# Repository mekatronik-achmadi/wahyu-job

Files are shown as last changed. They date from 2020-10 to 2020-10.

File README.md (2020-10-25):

This example test toolkit for various RF module.

###### SIM7000E
- [x] Own VDD
- [x] Serial Comm
- [x] Serial Prog
- [x] SIM Card Slot
- [x] GPS Antena
- [x] RF Antena
- [x] Boot-Config Pin
- [x] USB Firmware (R-USB Optional)
- [x] UART-FT232RL
- [x] UART-ESP32

###### ESP32-WROVER-IB
- [x] Own VDD
- [x] Serial Comm
- [x] Serial Prog
- [x] Boot-Config Pin
- [x] RTS-CTS Transistor
- [x] UART-FT232RL
- [x] UART-SIM7000

###### LORA SX1262
- [ ] Own VDD
- [ ] Serial Comm
- [ ] Serial Prog
- [ ] Boot-Config Pin

###### SIM800C
- [ ] Own VDD
- [ ] Serial Comm
- [ ] Serial Prog
- [ ] GPS Antena
- [ ] RF Antena
- [ ] Boot-Config Pin

###### FT232RL
- [x] Global VDD
- [x] Serial Comm
- [x] USB Port
- [x] UART Indicator (Optional)

###### AMS1117-3V3
- [x] Global VDD
- [x] Global VCC
- [x] VDD Selector

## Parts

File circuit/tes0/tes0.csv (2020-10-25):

Id | Designator | Package | Quantity | Designation | Supplier [Code] | Min Qty | URLs
1 | C-S70_ANT_GPS1,C-S70_ANT_GPS2 | C_0805_2012Metric_Pad1.15x1.40mm_HandSolder | 2 | 33pF | Tokopedia [Indoware] | 10 | https://www.tokopedia.com/indo-ware/0805-33pf-33-pf-50v-kapasitor-2012-smd-capasitor-33p-33-p-33-pf-33pf
2 | C-S70_ANT_RF1,C-S70_ANT_RF2 | C_0805_2012Metric_Pad1.15x1.40mm_HandSolder | 2 | C | Tokopedia [Indoware] | 10 | https://www.tokopedia.com/indo-ware/0805-33pf-33-pf-50v-kapasitor-2012-smd-capasitor-33p-33-p-33-pf-33pf
3 | R-S70_ANT_GPS1 | R_0805_2012Metric_Pad1.15x1.40mm_HandSolder | 1 | 10 | Tokopedia [Indoware] | 20 | https://www.tokopedia.com/indo-ware/10r-10-ohm-10-r-0805-1-resistor-smd-10ohm-10-ohm
4 | R-S70_ANT_RF1,R-S70_USB_VBUS1 | R_0805_2012Metric_Pad1.15x1.40mm_HandSolder | 2 | 0 | Tokopedia [Indoware] | 20 | https://www.tokopedia.com/indo-ware/0r-0-ohm-0805-5-paket-1-pcs-resistor-smd-jumper-nol-ohm-jumper-2012
5 | R-S70_USIM1,R-S70_USIM2,R-S70_USIM3 | R_0805_2012Metric_Pad1.15x1.40mm_HandSolder | 3 | 22 | Tokopedia [Indoware] | 20 | https://www.tokopedia.com/indo-ware/22r-22-ohm-0805-5-paket-10-pcs-resistor-smd-1
6 | U3 | SOT-223-3_TabPin2 | 1 | AMS1117-3.3 | Tokopedia [Indoware] | 4 | https://www.tokopedia.com/indo-ware/ams-1117-33v-smd-ams1117-33-voltage-regulated-ic-sot-223-ldo-33v
7 | R-ESP32_BOOT1,R-ESP32_BOOT2 | R_0805_2012Metric_Pad1.15x1.40mm_HandSolder | 2 | 100 | Tokopedia [Indoware] | 10 | https://www.tokopedia.com/indo-ware/100r-100-ohm-0805-5-paket-10-pcs-resistor-smd
8 | C-AMS1,C-AMS2,C-FT_3V3 | C_0805_2012Metric_Pad1.15x1.40mm_HandSolder | 3 | 100nF | Tokopedia | 2 (20) | https://www.tokopedia.com/tentronik/10-pcs-c-capasitor-100nf-100-nf-0-1uf-50v-smd-0805-10
9 | J-S70_ANT_GPS1,J-S70_ANT_RF1 | Taoglas-RECE-20279-001E-01-MFG | 2 | RECE-20279-001E-01 | Tokopedia | 10 | https://www.tokopedia.com/visitek/ipex-original-antenna-base-ipx-20279-001e-antena-u-fl-connector-0-4ghz
10 | L-S70_ANT_GPS1 | L_0805_2012Metric_Pad1.15x1.40mm_HandSolder | 1 | 47nH | Tokopedia | 10 | https://www.tokopedia.com/cosmic-iot/induktor-inductor-smd-47nh-47-nh-0805-error-5
11 | SW-S70-PWR1,SW-S70-RST1,SW-ESP32_RST1,SW-ESP32_RUN1 | SW_PUSH_6mm | 4 | SW_Push | Tokopedia | 10 | https://www.tokopedia.com/ahrar-1/push-button-saklar-kecil-tactile-tact-switch-micro-4pin-4p-6x6x5mm
12 | L-S70_ANT_GPS2,L-S70_ANT_GPS3 | L_0805_2012Metric_Pad1.15x1.40mm_HandSolder | 2 | L | Tokopedia | 10 | https://www.tokopedia.com/cosmic-iot/induktor-inductor-smd-47nh-47-nh-0805-error-5
13 | J-FT_USB1,J-S70-USB1 | USB_Micro-B_Wuerth_629105150521 | 2 | USB_B_Micro | Digiware [919-209] | 4 | https://digiwarestore.com/id/connector/micro-usb-connector-b-type-female-05p-smt-90-919209.html
14 | J-BRD_S70_FT1,J-BRD_ESP32_FT1,J-BRD_S70_ESP1 | PinHeader_2x02_P2.54mm_Vertical | 3 | Conn_02x02_Odd_Even | Digiware [323-074] | 4 | https://digiwarestore.com/id/pcb-male/header-40x2-kw2-323074.html
15 | J-ESP32_PB1,J-S70_PB1 | PinHeader_1x09_P2.54mm_Vertical | 2 | Conn_01x09 | Digiware [323-002] | 8 | https://digiwarestore.com/id/pcb-male/header-40x1-323002.html
16 | Q-ESP32_BOOT1,Q-ESP32_BOOT2 | SOT-23 | 2 | 2N3904 | Digiware [271-014] | 4 | https://digiwarestore.com/id/npn/mmbt3904lt1-smd-sot-23-10-pcs-per-pack-271014.html
17 | D-FT_RXD1,D-FT_TXD1,D-S70_NETLIGHT1,D-S70_STATUS1,D-ESP32_LED1 | LED_1206_3216Metric_Pad1.42x1.75mm_HandSolder | 5 | LED | Digiware [255-036] | 10 | https://digiwarestore.com/id/led/led-red-super-bright-smd1206-255036.html
18 | U2 | SSOP-28_5.3x10.2mm_P0.65mm | 1 | FT232RL | Digiware [166-019] | 3 | https://digiwarestore.com/id/serial-communication/ft232rl-166019.html
19 | U1 | SIMCON_SIM7000E | 1 | SIM7000E | Aliexpress | 2 | https://www.aliexpress.com/item/4001274551033.html
20 | J-S70_USIM1 | microSIM_JAE_SF53S006VCBR2000 | 1 | SIM_Card | Aliexpress | 6 | https://www.aliexpress.com/item/32793672605.html
21 | A1 | XCVR_ESP32-WROVER-I | 1 | ESP32-WROVER-I | Aliexpress | 2 | https://www.aliexpress.com/item/1005001544883473.html
22 | R-FT_RXD1,R-FT_TXD1,R-S70_NETLIGHT1,R-S70_STATUS1,R-ESP32_LED1 | R_0805_2012Metric_Pad1.15x1.40mm_HandSolder | 5 | 330 | Achmadi | 20 | -
23 | R-ESP32_IO2,R-ESP32_RST1 | R_0805_2012Metric_Pad1.15x1.40mm_HandSolder | 2 | 10K | Achmadi | 10 | -
24 | J-BRD_VDD1 | PinHeader_2x04_P2.54mm_Vertical | 1 | Conn_02x04_Odd_Even | - | - | -
25 | J-S70_PA1,J-S70_PC1 | PinHeader_1x06_P2.54mm_Vertical | 2 | Conn_01x06 | - | - | -
26 | J-S70_UART3 | PinHeader_1x03_P2.54mm_Vertical | 1 | Conn_01x03 | - | - | -
27 | J-S70_UPDATE1 | PinHeader_1x02_P2.54mm_Vertical | 1 | Conn_01x02 | - | - | -
28 | J-ESP32_PA1 | PinHeader_1x08_P2.54mm_Vertical | 1 | Conn_01x08 | - | - | -

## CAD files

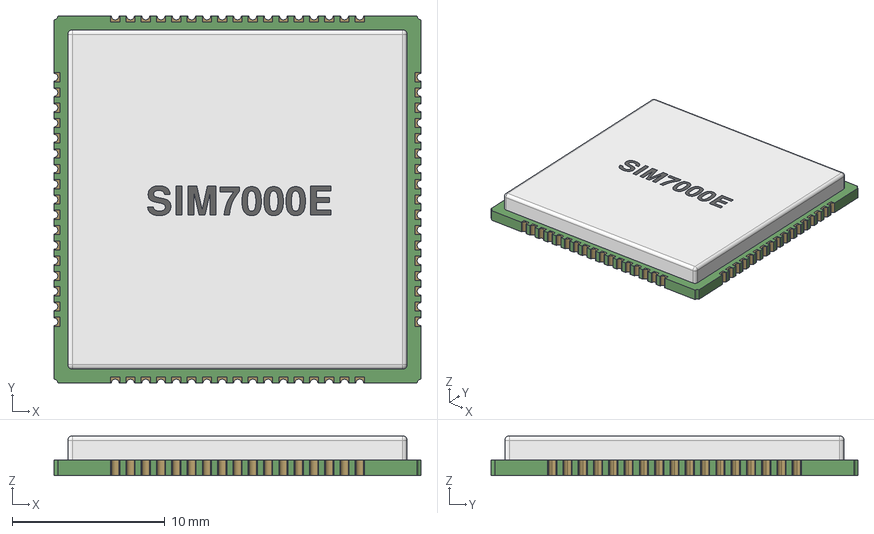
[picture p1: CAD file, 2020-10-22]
circuit/kicadlib/sim7000e/SIM7000.step
24.0 x 24.0 x 2.62 mm

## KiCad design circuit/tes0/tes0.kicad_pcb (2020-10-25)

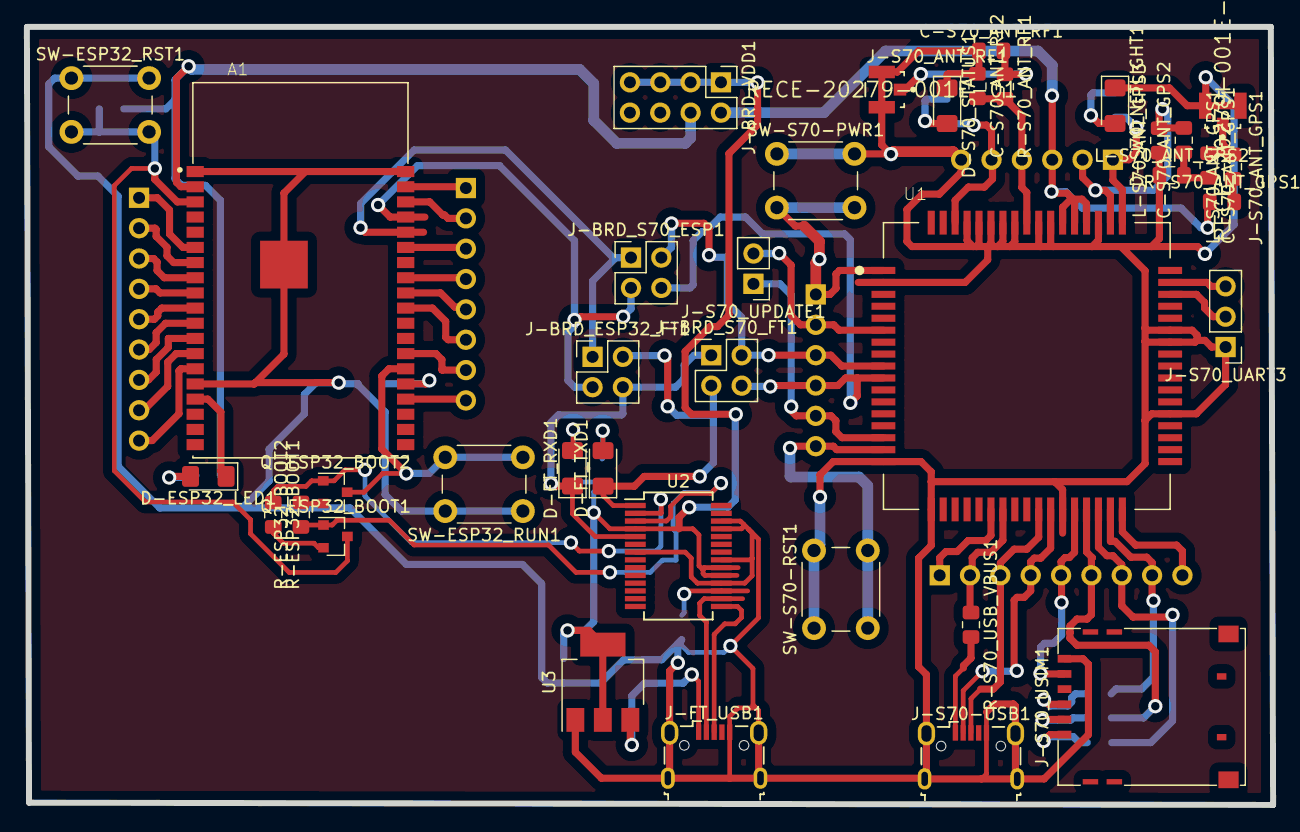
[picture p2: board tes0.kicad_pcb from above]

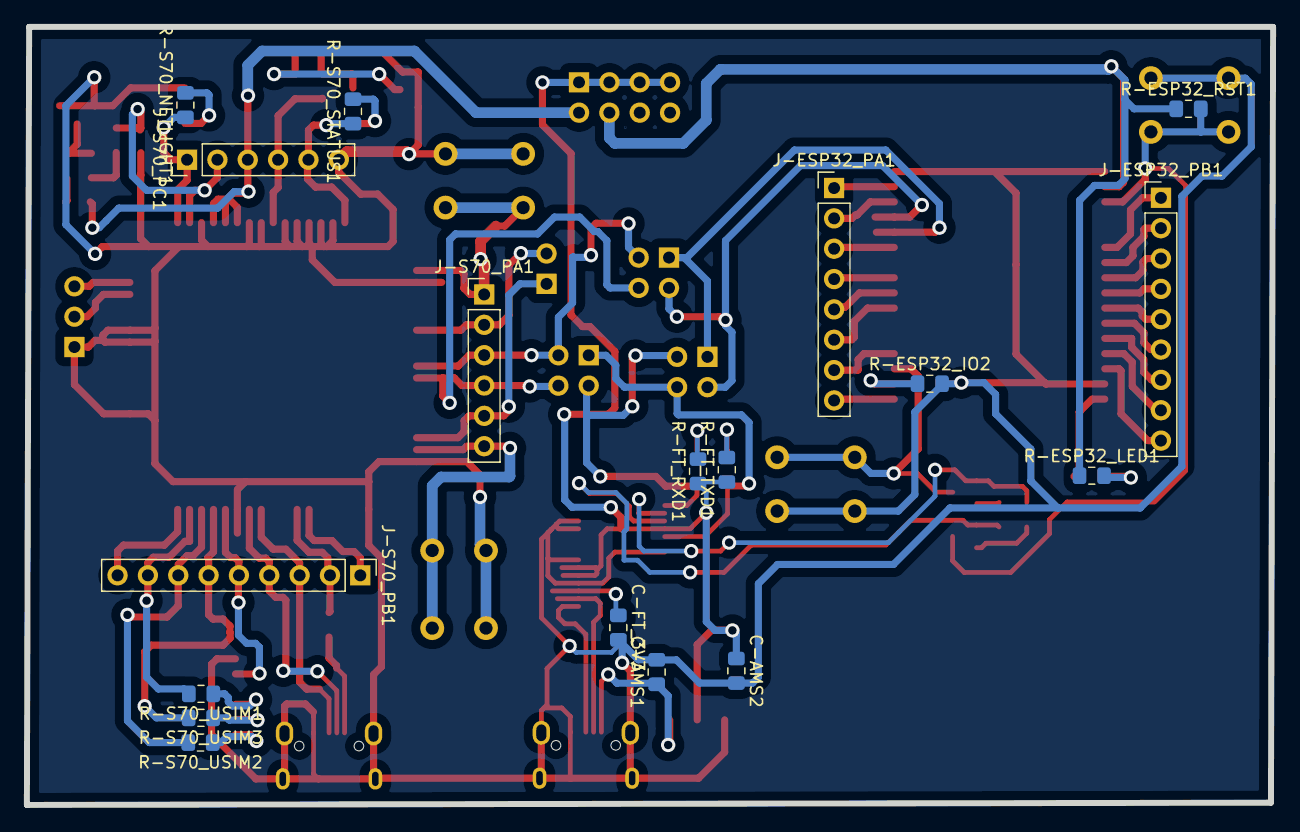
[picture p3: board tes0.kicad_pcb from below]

Board: 2 copper layers, 104.3 x 65.1 mm, 56 parts (18 on the bottom side), 71 nets.

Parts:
A1: ESP32-WROVER-I; XCVR_ESP32-WROVER-I
C-AMS1, C-AMS2: 100nF; C_0805_2012Metric_Pad1.15x1.40mm_HandSolder
C-FT_3V3: 100nF; C_0805_2012Metric_Pad1.15x1.40mm_HandSolder
C-S70_ANT_GPS1, C-S70_ANT_GPS2: 33pF; C_0805_2012Metric_Pad1.15x1.40mm_HandSolder
C-S70_ANT_RF1, C-S70_ANT_RF2: C; C_0805_2012Metric_Pad1.15x1.40mm_HandSolder
D-ESP32_LED1: LED; LED_1206_3216Metric_Pad1.42x1.75mm_HandSolder
D-FT_RXD1: LED; LED_1206_3216Metric_Pad1.42x1.75mm_HandSolder
D-FT_TXD1: LED; LED_1206_3216Metric_Pad1.42x1.75mm_HandSolder
D-S70_NETLIGHT1, D-S70_STATUS1: LED; LED_1206_3216Metric_Pad1.42x1.75mm_HandSolder
J-BRD_ESP32_FT1: Conn_02x02_Odd_Even; PinHeader_2x02_P2.54mm_Vertical
J-BRD_S70_ESP1, J-BRD_S70_FT1: Conn_02x02_Odd_Even; PinHeader_2x02_P2.54mm_Vertical
J-BRD_VDD1: Conn_02x04_Odd_Even; PinHeader_2x04_P2.54mm_Vertical
J-ESP32_PA1: Conn_01x08; PinHeader_1x08_P2.54mm_Vertical
J-ESP32_PB1: Conn_01x09; PinHeader_1x09_P2.54mm_Vertical
J-FT_USB1: USB_B_Micro; USB_Micro-B_Wuerth_629105150521
J-S70-USB1: USB_B_Micro; USB_Micro-B_Wuerth_629105150521
J-S70_ANT_GPS1, J-S70_ANT_RF1: RECE-20279-001E-01; Taoglas-RECE-20279-001E-01-MFG
J-S70_PA1, J-S70_PC1: Conn_01x06; PinHeader_1x06_P2.54mm_Vertical
J-S70_PB1: Conn_01x09; PinHeader_1x09_P2.54mm_Vertical
J-S70_UART3: Conn_01x03; PinHeader_1x03_P2.54mm_Vertical
J-S70_UPDATE1: Conn_01x02; PinHeader_1x02_P2.54mm_Vertical
J-S70_USIM1: SIM_Card; microSIM_JAE_SF53S006VCBR2000
L-S70_ANT_GPS1: 47nH; L_0805_2012Metric_Pad1.15x1.40mm_HandSolder
L-S70_ANT_GPS2, L-S70_ANT_GPS3: L; L_0805_2012Metric_Pad1.15x1.40mm_HandSolder
Q-ESP32_BOOT1, Q-ESP32_BOOT2: 2N3904; SOT-23
R-ESP32_BOOT1, R-ESP32_BOOT2: 100; R_0805_2012Metric_Pad1.15x1.40mm_HandSolder
R-ESP32_IO2, R-ESP32_RST1: 10K; R_0805_2012Metric_Pad1.15x1.40mm_HandSolder
R-ESP32_LED1: 330; R_0805_2012Metric_Pad1.15x1.40mm_HandSolder
R-FT_RXD1: 330; R_0805_2012Metric_Pad1.15x1.40mm_HandSolder
R-FT_TXD1: 330; R_0805_2012Metric_Pad1.15x1.40mm_HandSolder
R-S70_ANT_GPS1: 10; R_0805_2012Metric_Pad1.15x1.40mm_HandSolder
R-S70_ANT_RF1, R-S70_USB_VBUS1: 0; R_0805_2012Metric_Pad1.15x1.40mm_HandSolder
R-S70_NETLIGHT1, R-S70_STATUS1: 330; R_0805_2012Metric_Pad1.15x1.40mm_HandSolder
R-S70_USIM1, R-S70_USIM2, R-S70_USIM3: 22; R_0805_2012Metric_Pad1.15x1.40mm_HandSolder
SW-ESP32_RST1, SW-ESP32_RUN1: SW_Push; SW_PUSH_6mm
SW-S70-PWR1, SW-S70-RST1: SW_Push; SW_PUSH_6mm
U1: SIM7000E; SIMCON_SIM7000E
U2: FT232RL; SSOP-28_5.3x10.2mm_P0.65mm
U3: AMS1117-3.3; SOT-223-3_TabPin2

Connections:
/ESP32_BOOT: A1.25, Q-ESP32_BOOT2.3, SW-ESP32_RUN1.2
/ESP32_IO4: A1.26, J-ESP32_PA1.7
/ESP32_IO5: A1.29, J-ESP32_PA1.6
/ESP32_IO12: A1.14, J-ESP32_PB1.9
/ESP32_IO14: A1.13, J-ESP32_PB1.8
/ESP32_IO15: A1.23, J-ESP32_PA1.8
/ESP32_IO18: A1.30, J-ESP32_PA1.5
/ESP32_IO19: A1.31, J-ESP32_PA1.4
/ESP32_IO21: A1.33, J-ESP32_PA1.3
/ESP32_IO22: A1.36, J-ESP32_PA1.2
/ESP32_IO23: A1.37, J-ESP32_PA1.1
/ESP32_IO25: A1.10, J-ESP32_PB1.5
/ESP32_IO26: A1.11, J-ESP32_PB1.6
/ESP32_IO27: A1.12, J-ESP32_PB1.7
/ESP32_IO32: A1.8, J-ESP32_PB1.3
/ESP32_IO33: A1.9, J-ESP32_PB1.4
/ESP32_IO34: A1.6, J-ESP32_PB1.1
/ESP32_IO35: A1.7, J-ESP32_PB1.2
/ESP32_LED: A1.16, D-ESP32_LED1.1
/ESP32_RST: A1.3, Q-ESP32_BOOT1.3, R-ESP32_RST1.2, SW-ESP32_RST1.2
/ESP32_RXD: A1.34, J-BRD_ESP32_FT1.1, J-BRD_S70_ESP1.1
/ESP32_TXD: A1.35, J-BRD_ESP32_FT1.3, J-BRD_S70_ESP1.3
/ESP32_VDD: A1.2, J-BRD_VDD1.4, R-ESP32_LED1.1, R-ESP32_RST1.1
/FT_DTR: Q-ESP32_BOOT2.1, R-ESP32_BOOT1.1, U2.2
/FT_RTS: Q-ESP32_BOOT1.1, R-ESP32_BOOT2.1, U2.3
/FT_RXD: D-FT_RXD1.1, J-BRD_ESP32_FT1.4, J-BRD_S70_FT1.1, U2.5
/FT_TXD: D-FT_TXD1.1, J-BRD_ESP32_FT1.2, J-BRD_S70_FT1.3, U2.1
/S70_ANT_GPS: C-S70_ANT_GPS2.2, J-S70_PC1.2, L-S70_ANT_GPS3.2, U1.53
/S70_ANT_RF: C-S70_ANT_RF2.2, J-S70_PC1.4, R-S70_ANT_RF1.2, U1.60
/S70_BOOTCFG: J-S70_PA1.2, J-S70_UPDATE1.2, U1.6
/S70_GPIO0: J-S70_UART3.3, U1.50
/S70_GPIO1: J-S70_UART3.2, U1.49
/S70_MDMLOG_TX: J-S70_PB1.1, U1.23
/S70_NETLIGHT: J-S70_PC1.1, R-S70_NETLIGHT1.1, U1.52
/S70_NRST: J-S70_PA1.6, SW-S70-RST1.2, U1.16
/S70_PWRKEY: J-S70_PA1.1, SW-S70-PWR1.2, U1.1
/S70_RXD: J-BRD_S70_ESP1.4, J-BRD_S70_FT1.4, J-S70_PA1.4, U1.10
/S70_STATUS: J-S70_PC1.5, R-S70_STATUS1.1, U1.66
/S70_TXD: J-BRD_S70_ESP1.2, J-BRD_S70_FT1.2, J-S70_PA1.3, U1.9
/S70_USB_DM: J-S70-USB1.2, J-S70_PB1.4, U1.28
/S70_USB_DP: J-S70-USB1.3, J-S70_PB1.3, U1.27
/S70_USB_VBUS: J-S70_PB1.2, R-S70_USB_VBUS1.1, U1.24
/S70_USIM_CLK: J-S70_PB1.7, R-S70_USIM2.2, U1.32
/S70_USIM_DATA: J-S70_PB1.6, R-S70_USIM3.2, U1.31
/S70_USIM_DET: J-S70_PB1.9, U1.34
/S70_USIM_RST: J-S70_PB1.8, R-S70_USIM1.2, U1.33
/S70_USIM_VDD: J-S70_PB1.5, J-S70_USIM1.1, U1.30
/S70_VDD: J-BRD_VDD1.2, J-S70_PC1.3, R-S70_ANT_GPS1.1, U1.55, U1.56, U1.57
/S70_VDDEXT: J-S70_PA1.5, J-S70_UPDATE1.1, U1.15
GND: A1.1, A1.15, A1.38, A1.39, C-AMS1.2, C-AMS2.2, C-FT_3V3.2, C-S70_ANT_RF1.1, C-S70_ANT_RF2.1, D-S70_NETLIGHT1.1, D-S70_STATUS1.1, J-FT_USB1.5, J-FT_USB1.6, J-S70-USB1.5, J-S70-USB1.6, J-S70_ANT_GPS1.2, J-S70_ANT_GPS1.3, J-S70_ANT_RF1.2, J-S70_ANT_RF1.3, J-S70_PC1.6, J-S70_UART3.1, J-S70_USIM1.5, L-S70_ANT_GPS2.1, L-S70_ANT_GPS3.1, R-ESP32_IO2.2, SW-ESP32_RST1.1, SW-ESP32_RUN1.1, SW-S70-PWR1.1, SW-S70-RST1.1, U1.2, U1.17, U1.18, U1.29, U1.39, U1.45, U1.46, U1.54, U1.58, U1.59, U1.61, U1.62, U1.63, U1.64, U1.65, U2.7, U2.18, U2.21, U2.25, U2.26, U3.1
unnamed: A1.24, R-ESP32_IO2.1
unnamed: C-FT_3V3.1, U2.17
unnamed: C-S70_ANT_GPS1.1, J-S70_ANT_GPS1.1, L-S70_ANT_GPS1.2
unnamed: C-S70_ANT_GPS1.2, C-S70_ANT_GPS2.1, L-S70_ANT_GPS2.2
unnamed: C-S70_ANT_RF1.2, J-S70_ANT_RF1.1, R-S70_ANT_RF1.1
unnamed: D-ESP32_LED1.2, R-ESP32_LED1.2
unnamed: D-FT_RXD1.2, R-FT_TXD1.2
unnamed: D-FT_TXD1.2, R-FT_RXD1.2
unnamed: D-S70_NETLIGHT1.2, R-S70_NETLIGHT1.2
unnamed: D-S70_STATUS1.2, R-S70_STATUS1.2
unnamed: J-FT_USB1.2, U2.16
unnamed: J-FT_USB1.3, U2.15
unnamed: J-S70-USB1.1, R-S70_USB_VBUS1.2
unnamed: J-S70_USIM1.2, R-S70_USIM1.1
unnamed: J-S70_USIM1.3, R-S70_USIM2.1
unnamed: J-S70_USIM1.7, R-S70_USIM3.1
unnamed: L-S70_ANT_GPS1.1, R-S70_ANT_GPS1.2
unnamed: Q-ESP32_BOOT1.2, R-ESP32_BOOT1.2
unnamed: Q-ESP32_BOOT2.2, R-ESP32_BOOT2.2
VCC: C-AMS1.1, J-FT_USB1.1, U3.3
VDD: C-AMS2.1, J-BRD_VDD1.1, J-BRD_VDD1.3, J-BRD_VDD1.5, J-BRD_VDD1.7, R-FT_RXD1.1, R-FT_TXD1.1, U2.4, U2.19, U2.20, U3.2

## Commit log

2020-10-22 sim7000e basic
    [SIM7000.step, tes0.kicad_pcb, tes0.sch]
2020-10-22 sim7000e minus antena
    [tes0.kicad_pcb, tes0.sch]
2020-10-23 add FT232RL
    [tes0.kicad_pcb, tes0.sch]
2020-10-24 update ikut skematik datasheet
    [tes0.kicad_pcb, tes0.sch]
2020-10-25 basic ESP32+SIM7000
    [tes0.kicad_pcb, tes0.sch]
